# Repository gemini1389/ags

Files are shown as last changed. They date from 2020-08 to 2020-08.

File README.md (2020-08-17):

## Active Grille Shutter
Arduino Due project for Active Grille Shutter (AGS) control.

The project was made for a Honda CR-V 5 gen with a 2.4l engine in a configuration without AGS.

Due to circumstances, the project did not get into production, there was no longer a need for it. This is a beta version of the project, in which a lot can be optimized and/or rewritten.

The shutter opening and closing algorithm is primitive and solves the problem of faster engine heating in cold weather.

Added code to close curtains at high speed to increase vehicle aerodynamics. The code for closing the curtains at high speed has not been tested and needs optimization:
- selection of the maximum temperature for opening the curtains
- selection of vehicle speed for closing
- the delay between opening and closing the shutters at high speed
- automatic shutter opening after engine stop

### Libraries for Arduino IDE:
- [Adafruit GFX Library](https://github.com/adafruit/Adafruit-GFX-Library)
- [Adafruit_SSD1306](https://github.com/adafruit/Adafruit_SSD1306)
- [CAN BUS Shield](https://github.com/Seeed-Studio/CAN_BUS_Shield)
- [Servo](https://www.arduino.cc/reference/en/libraries/servo/)
- [SPI](https://www.arduino.cc/en/reference/SPI)

### Hardware:
- Arduino Due
- Sparkfun S05NF (micro) with upgrade
- 0.96" OLED Display Module 128X64 I2C
- CAN Module MCP2515
- Dupont wires
- Breadboard
- Micro USB Cable
- DC 9V 1A Power Supply Adapter 5.5x2.1mm

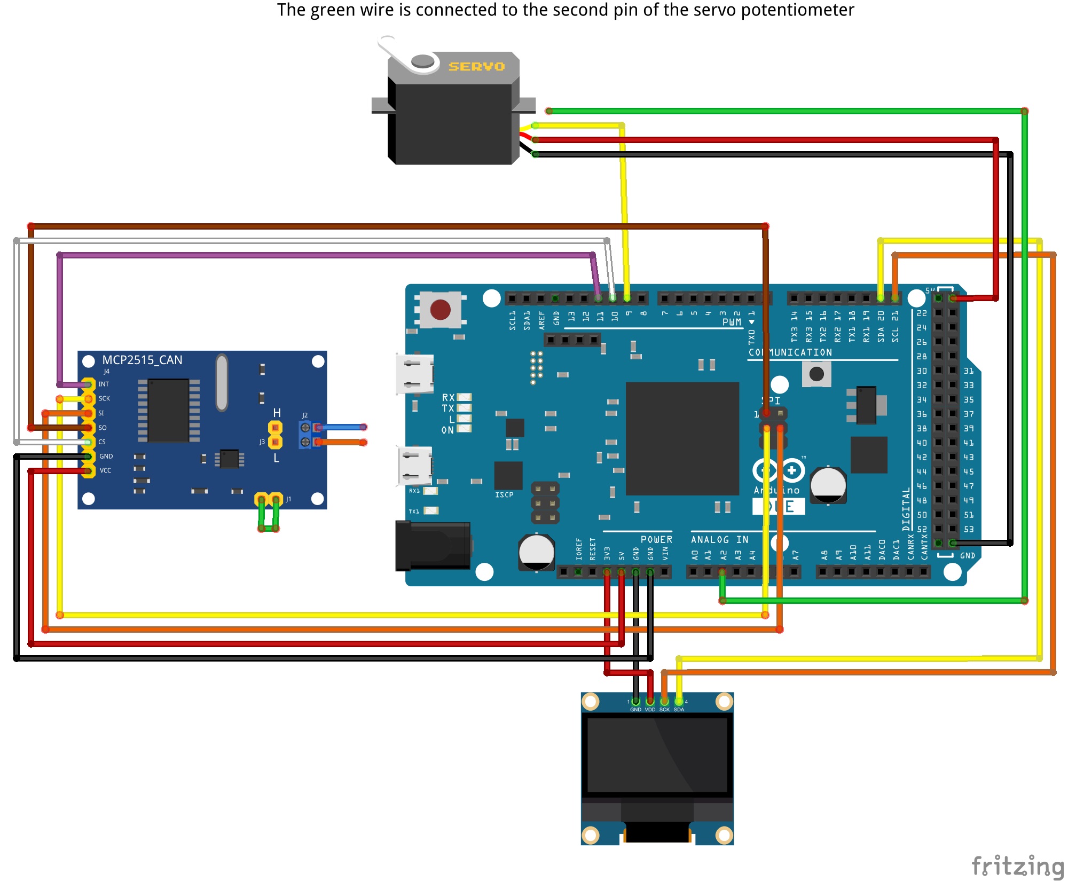
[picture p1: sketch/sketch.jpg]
scheme


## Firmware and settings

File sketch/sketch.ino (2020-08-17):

/**
   https://github.com/adafruit/Adafruit-GFX-Library
   Commit: 0752d4bd4f35407684c1123e618368719b95ec22

   https://github.com/adafruit/Adafruit_SSD1306
   Commit: d62796bbe860e046265ba1251a0bf89b15e3481e

   https://github.com/Seeed-Studio/CAN_BUS_Shield
   Commit: edaba2d87efc597770079d6ed63f09aa246eba29
*/
#include <Adafruit_GFX.h>
#include <Adafruit_SSD1306.h>
#include <Servo.h>
#include <SPI.h>
#include <mcp_can.h>

// Print messages to Serial
#define DEBUG_MODE true

// GPIO the display is attached to
#define pinCanCs        10
#define pinCanInt       11
const int SPI_CS_PIN = pinCanCs;
const int INT_PIN = pinCanInt;

// Change this values if you are using a custom font
#define DEFAULT_SYMBOL_WIDTH  6
#define DEFAULT_SYMBOL_HEIGHT 8

// OLED display width and height, in pixels
#define SCREEN_WIDTH  128
#define SCREEN_HEIGHT 64

// GPIO the display is attached to
#define pinDisplaySDA 20
#define pinDisplaySCL 21

// GPIO the servo is attached to
#define pinServo        9
#define pinServoAnalog  A2

// Config for servo
#define servoDelay        8
#define servoDiagDelay    30
#define servoMinUs        720  // 0
#define servoMaxUs        2400 // 180
#define servoMaxAttempts  3

// Min and max degree for rotation servo
#define servoDegreeMin  45
#define servoDegreeMax  105

// Min and max analog values
#define servoAnalogMin  330
#define servoAnalogMax  480

// Possible difference between values
#define servoAnalogDegreesDiff  5
#define servoAnalogAnalogDiff   50

// Progress Bar
#define textSize                2
#define progressBarTextSize     2
#define progressBarBorder       1   // px
#define progressBarMarginOuter  13  // px
#define progressBarHeightOuter  13  // px
#define progressBarLengthOuter  (SCREEN_WIDTH - progressBarMarginOuter * 2)
#define progressBarMarginInner  progressBarMarginOuter + progressBarBorder
#define progressBarHeightInner  progressBarHeightOuter - progressBarBorder * 2
#define progressBarLengthInner  progressBarLengthOuter - (progressBarBorder * 2)

Adafruit_SSD1306 display(SCREEN_WIDTH, SCREEN_HEIGHT, &Wire);
Servo servo;
MCP_CAN CAN(pinCanCs);

bool isDataUpdated = false;

float engineTemp;
float carSpeed;
int shutterDegree;

int newDegree = servoDegreeMin;
int analogDegree;
unsigned long timer;

volatile bool hasNewMessage = false;
unsigned char len = 0;
unsigned char buf[8];

void drawProgressBar(int y, int progress, int margin = 13, int height = 13);
bool writeServo(int degree, bool isDiagnostics = false);

void setup() {
  if (DEBUG_MODE) {
    Serial.begin(115200);
  }
  println("[INIT] Debug mode is enabled");
  println("[INIT] Starting...");

  initDisplay();
  println("--------------");
  initCan();
  println("--------------");
  initServo();
  println("--------------");
  servoDiagnostics();

  println("[INIT] Initialization is complete");

  renderAllData();
}

void loop() {
  while (CAN_MSGAVAIL == CAN.checkReceive()) {
    CAN.readMsgBuf(&len, buf);
    canMessageProcessing(CAN.getCanId(), buf);
  }

  if (isDataUpdated) {
    isDataUpdated = false;
    openCloseShutters();
    renderAllData();
  }
}

// Open or close grille shutters
void openCloseShutters() {
  float temp = getEngineTemp();
  float speed = getSpeed();
  bool openShutters = true;

  if (temp < 70) {
    openShutters = false;
  }

  if (speed > 130) {
    openShutters = (temp > 90);
  }

  print("[INFO] Shutters must be ");
  print(String(openShutters ? servoDegreeMin : servoDegreeMax));
  print(" ");
  print("(" + String(openShutters ? "open" : "close") + ")");
  println("");

  int degreeNeedle = openShutters ? servoDegreeMin : servoDegreeMax;
  if (!isServoRotated(degreeNeedle)) {
    writeServo(degreeNeedle);
  }
}

void renderAllData() {
  display.setTextSize(textSize);
  display.clearDisplay();

  renderEngineTemp();
  renderCarSpeed();
  renderProgressBar();

  display.display();
}

void renderEngineTemp() {
  display.setCursor(0, 0);
  display.println(String(getEngineTemp(), 1) + " oC");
}

void renderCarSpeed() {
  display.setCursor(0, 16);
  display.println(String(getSpeed(), 1) + " km/h");
}

void renderProgressBar() {
  int shutterDegrees = getShutterDegree();
  int progress = map(shutterDegrees, servoDegreeMin, servoDegreeMax, 0, progressBarLengthInner);
  String text = String(shutterDegrees);
  int y = constrain(51, 0, SCREEN_HEIGHT);
  int x = (SCREEN_WIDTH - text.length() * DEFAULT_SYMBOL_WIDTH * progressBarTextSize) / 2;

  display.setTextSize(progressBarTextSize);
  display.setCursor(x, y - DEFAULT_SYMBOL_HEIGHT * progressBarTextSize);
  display.println(text);

  display.drawRect(
    progressBarMarginOuter,
    y,
    progressBarLengthOuter,
    progressBarHeightOuter,
    HIGH
  );
  display.fillRect(
    progressBarMarginInner,
    y + progressBarBorder,
    progress ? : progressBarLengthInner,
    progressBarHeightInner,
    progress ? HIGH : LOW
  );
  display.display();
}

float getEngineTemp() {
  return engineTemp;
}

float getSpeed() {
  return carSpeed;
}

int getShutterDegree() {
  return shutterDegree;
}

// CAN message processing
void canMessageProcessing(unsigned long messageId, byte* messageData) {
  String id = String(messageId, HEX);

  // Engine temp
  if (id == "324") {
    float engineTempOld = getEngineTemp();

    engineTemp = messageData[0] - 40.0;

    if (engineTempOld != engineTemp) {
      isDataUpdated = true;

      println("EngineTemp: " + String(getEngineTemp()));
    }
  }
  // Speeds (general)
  else if (id == "158") {
    float carSpeedOld = getSpeed();

    carSpeed = (messageData[0] * 256 + messageData[1]) / 100.0;

    if (carSpeedOld != carSpeed) {
      isDataUpdated = true;

      println("Speed: " + String(getSpeed()));
    }
  }
}

// Returns analog degree for servo
int getAnalogDegree() {
  int analogVal = analogRead(pinServoAnalog);
  analogVal = constrain(analogVal, servoAnalogMin, servoAnalogMax);
  analogDegree = map(analogVal, servoAnalogMin, servoAnalogMax, servoDegreeMin, servoDegreeMax);

  return analogDegree;
}

// It returns the status of whether the servo turned
bool isServoRotated(int degreeNeedle) {
  bool rotated = false;

  // Check by analog value
  int analogVal = analogRead(pinServoAnalog);
  int checkMinAnalog = servoAnalogMin - servoAnalogAnalogDiff;
  int checkMaxAnalog = servoAnalogMax + servoAnalogAnalogDiff;
  rotated = analogVal > checkMinAnalog && analogVal < checkMaxAnalog;

  print("[INFO] Analog: ");
  print(String(analogVal));
  println(" | Diff min: " + String(checkMinAnalog) + " | Diff max: " + String(checkMaxAnalog));

  // Check by digital value
  if (rotated) {
    int degreeAnalog = getAnalogDegree();
    int checkMin = degreeNeedle - servoAnalogDegreesDiff;
    int checkMax = degreeNeedle + servoAnalogDegreesDiff;
    rotated = degreeAnalog > checkMin && degreeAnalog < checkMax;

    print("[INFO] Digital: ");
    print(String(degreeAnalog) + "/" + String(degreeNeedle) + " (Analog/Digital)");
    println(" | Diff min: " + String(checkMin) + " | Diff max: " + String(checkMax));
  }

  println(rotated ? "[OK] Servo is rotated!" : "[FAIL] Servo is not rotated!");

  return rotated;
}

// Rotate servo
bool writeServo(int degree, bool isDiagnostics) {
  int start = getAnalogDegree();
  int end = degree;
  int position;

  if (start > end) {
    for (position = start; position >= end; position--)
    {
      servo.write(position);
      delay(isDiagnostics ? servoDiagDelay : servoDelay);
    }
  } else {
    for (position = start; position <= end; position++)
    {
      servo.write(position);
      delay(isDiagnostics ? servoDiagDelay : servoDelay);
    }
  }

  delay(300);

  shutterDegree = constrain(getAnalogDegree(), servoDegreeMin, servoDegreeMax);

  return isServoRotated(degree);
}

// Display initialization
void initDisplay() {
  if (!display.begin(SSD1306_SWITCHCAPVCC, 0x3C)) {
    println("[FAIL] SSD1306 allocation failed");
    for (;;);
  }
  println("[OK] SSD1306 allocation successful");

  display.clearDisplay();
  display.setTextColor(HIGH, LOW);
  display.display();

  println("[INIT] Display initialized");
}

// CAN bus initialization
void initCan() {
  while (CAN_OK != CAN.begin(CAN_500KBPS, MCP_8MHz)) {
    println("[FAIL] CAN BUS module init fail");
    println("[FAIL] Init CAN BUS module again");
    delay(100);
  }

  println("[INIT] CAN initialized");

  // Hardware filters
  CAN.init_Mask(0, 0, 0x158);
  CAN.init_Mask(1, 0, 0x324);
  CAN.init_Filt(0, 0, 0x158);
  CAN.init_Filt(1, 0, 0x324);

  println("[INIT] CAN filters added");
}

// Servo initialization
void initServo() {
  pinMode(pinServoAnalog, INPUT);

  servo.attach(
    pinServo,
    servoMinUs,
    servoMaxUs
  );

  if (servo.attached()) {
    println("[INIT] Servo attached");
  }

  writeServo(newDegree);
}

// Diagnostics for servo
void servoDiagnostics() {
  display.setCursor(0, 0);
  display.println("Servo diag: start");
  display.display();

  println("[INIT] Servo diagnostics: start");

  bool diagStatus = true;
  diagStatus = writeServo(servoDegreeMax, true);

  display.println("Servo diag #1: " + String(diagStatus ? "OK" : "FAIL"));
  display.display();

  print(diagStatus ? "[OK]" : "[FAIL]");
  println(" Servo diagnostics #1 (to " + String(servoDegreeMax) + "°)");

  if (diagStatus) {
    diagStatus = writeServo(servoDegreeMin, true);
  }

  display.println("Servo diag #2: " + String(diagStatus ? "OK" : "FAIL"));
  display.display();

  print(diagStatus ? "[OK]" : "[FAIL]");
  println(" Servo diagnostics #2 (to " + String(servoDegreeMin) + "°)");

  if (diagStatus) {
    diagStatus = writeServo(servoDegreeMax, true);
  }

  display.println("Servo diag #3: " + String(diagStatus ? "OK" : "FAIL"));
  display.display();

  print(diagStatus ? "[OK]" : "[FAIL]");
  println(" Servo diagnostics #3 (to " + String(servoDegreeMax) + "°)");

  if (diagStatus) {
    diagStatus = writeServo(servoDegreeMin, true);
  }

  display.println("Servo diag #4: " + String(diagStatus ? "OK" : "FAIL"));
  display.display();

  print(diagStatus ? "[OK]" : "[FAIL]");
  println(" Servo diagnostics #4 (to " + String(servoDegreeMin) + "°)");

  if (!diagStatus) {
    while (true) {
      if (millis() - timer >= 3000) {
        timer = millis();

        display.println("");
        display.println("Life Is Pain");
        display.println("Shit happens...");
        display.display();

        println("[FAIL] Servo diagnostics: Shit happens...");
      }
    }
  }

  display.println("");
  display.println("Success!");
  display.display();

  println("[INIT] Servo diagnostics: success");
}

// Print message to Serial
void print(String message) {
  if (DEBUG_MODE) {
    Serial.print(message);
  }
}

// Print message to Serial
void println(String message) {
  if (DEBUG_MODE) {
    Serial.println(message);
  }
}

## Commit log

2020-08-15 Added scheme and Fritzing file
    [sketch.fzz]
2020-08-17 Updated code sketch and README.md
    [sketch.fzz]
